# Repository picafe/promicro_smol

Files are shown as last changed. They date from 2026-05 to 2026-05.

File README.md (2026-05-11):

# promicro_smol

`promicro_smol` is a compact shield PCB for the nRF52840 Supermini/Pro Micro used in DIY SlimeVR trackers. It has an IMU, magnetometer, two buttons, RGB LED, battery pads and voltage reading functionality. It is designed to be compatible with existing Chrysalis enclosures (not yet verified). Production files can be found in `/pcb/production/`.

## Why I Made This

This project started as a modification of Chrysalis to support operation at 1.8V logic and to add a few features. The main changes were to make the magnetometer support 1.8V logic, switch to a MOSFET-controlled RGB LED, add a battery voltage divider for better capacity measurement, and to make sure SWD pads are accessible through a board cutout. I made these changes ensuring the board is optimized for JLCPCB economic assembly.

## Pictures

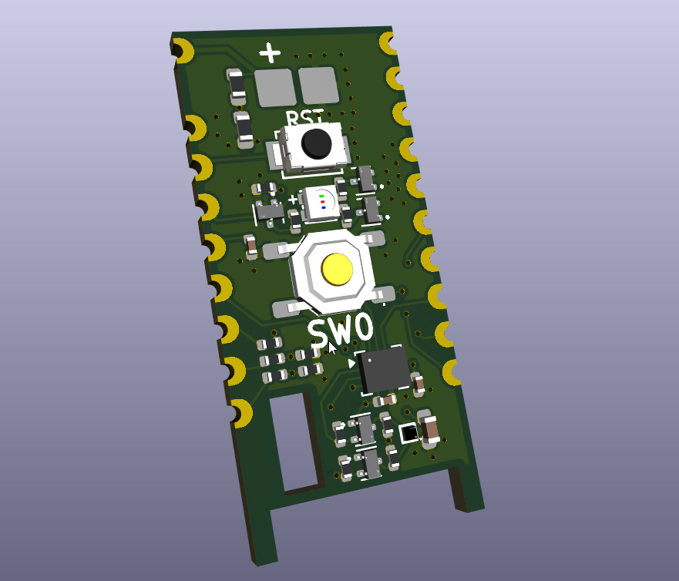
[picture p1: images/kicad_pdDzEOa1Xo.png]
3D Model


### Schematic
[View Online](https://kicanvas.org/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)

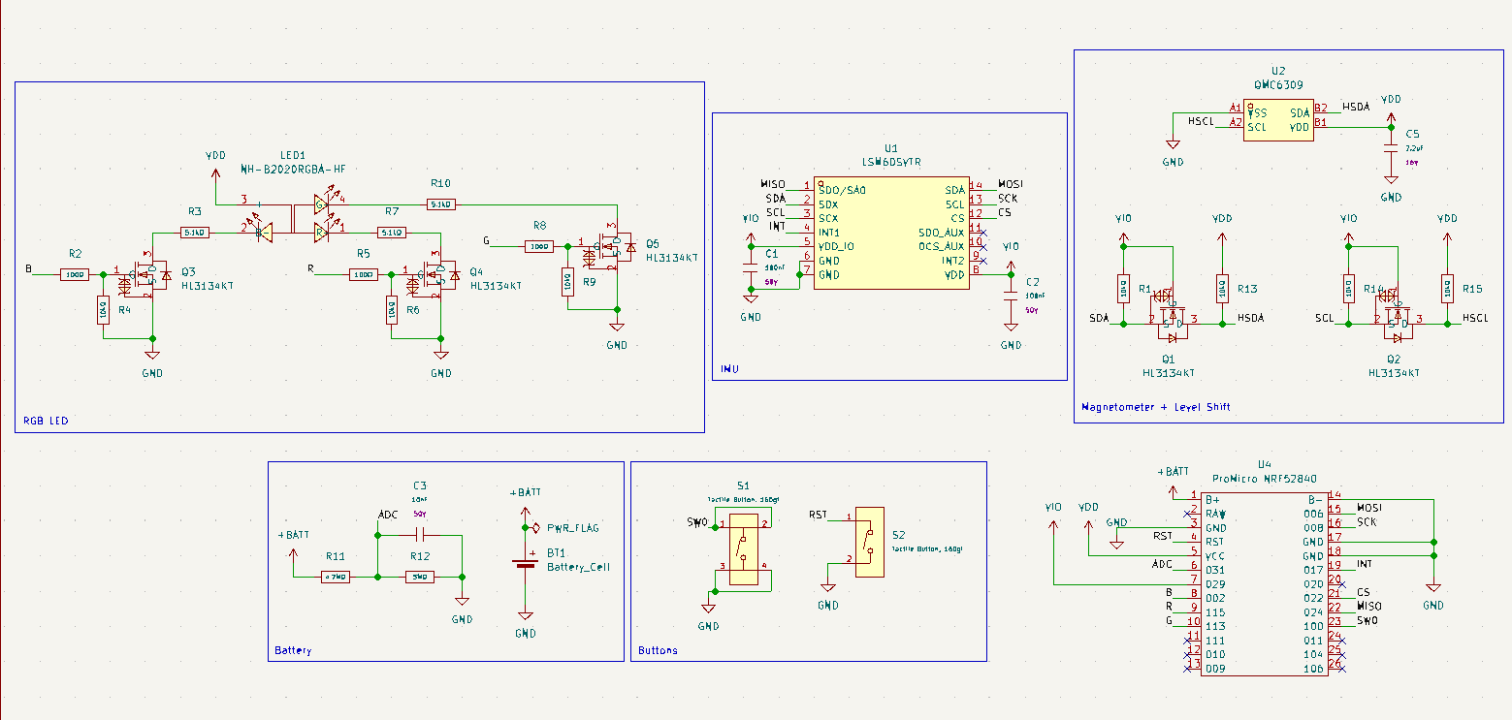
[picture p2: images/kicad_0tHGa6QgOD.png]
Schematic Image

### PCB
[View Online](https://kicanvas.org/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)

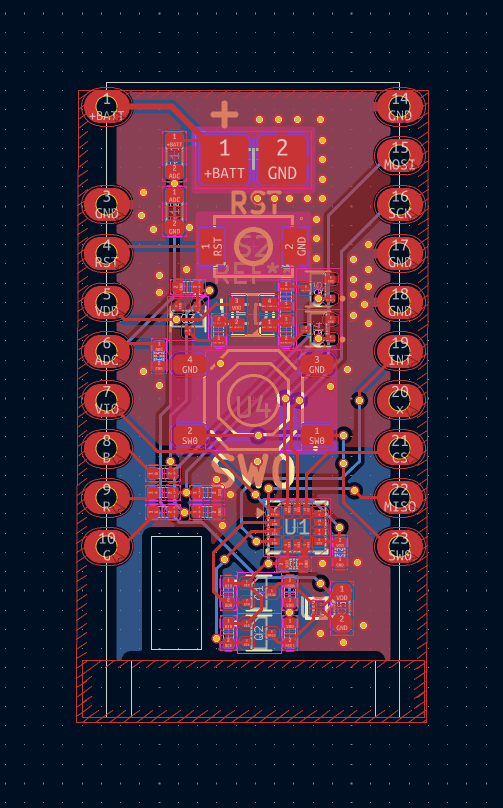
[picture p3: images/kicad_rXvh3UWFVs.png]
PCB Image


## Credits and Attribution

This work is derived from the [kounocom/Chrysalis](https://github.com/kounocom/Chrysalis) hardware project.

Files from `/pcb/Chrysalis-Footprints.pretty` are sourced from the Chrysalis project with and without modifications.

The upstream project is provided under CERN-OHL-S-2.0, and this repository includes the applicable license text in `LICENSE.md`.

## Bill of Materials

LCSC and other supplier pricing moves with stock, demand, quantity, and exchange rates. Treat **Unit cost** and **Total cost** as a very rough estimate. For example, the LSM6DSV has increased in price significantly in the past few months due to shortages and decreasing stock.

| Item | Value / Part | Quantity | Unit cost | Total cost |
| --- | --- | --- | --- | --- |
| MCU module | ProMicro nRF52840 (can be found on Aliexpress) | 1 | $3 | $3 |
| IMU | [LSM6DSVQTR (C17496470)](https://www.lcsc.com/product-detail/C17496470.html) | 1 | $2.27 | $2.27 |
| Magnetometer | [QMC6309 (C5439871)](https://www.lcsc.com/product-detail/C5439871.html) | 1 | $0.36 | $0.36 |
| N-FETs | [HL3134KT (C52204685)](https://www.lcsc.com/product-detail/C52204685.html) | 5 | $0.03 | $0.15 |
| RGB LED | [NH-B2020RGBA-HF (C2874116)](https://www.lcsc.com/product-detail/C2874116.html) | 1 | $0.01 | $0.01 |
| Push buttons | [Tactile Button, 160gf (C318884)](https://www.lcsc.com/product-detail/C318884.html), [Tactile Button, 160gf (C720477)](https://www.lcsc.com/product-detail/C720477.html) | 2 | $0.07 | $0.14 |
| Resistors | [100R (C25076)](https://www.lcsc.com/product-detail/C25076.html), [5.1k (C25905)](https://www.lcsc.com/product-detail/C25905.html), [10k (C25744)](https://www.lcsc.com/product-detail/C25744.html), [3M (C23156)](https://www.lcsc.com/product-detail/C23156.html), [4.7M (C23163)](https://www.lcsc.com/product-detail/C23163.html) | 12 | $0.01 | $0.12 |
| Capacitors | [100nF (C307331)](https://www.lcsc.com/product-detail/C307331.html), [10nF (C15195)](https://www.lcsc.com/product-detail/C15195.html), [2.2uF (C23630)](https://www.lcsc.com/product-detail/C23630.html) | 4 | $0.01 | $0.04 |

**Approximate component cost for 1 board:** ~$6.09

**PCB fabrication and assembly:** JLCPCB, 2 boards PCBA, 0.8 mm, lead-free HASL — about US$40 (your quote will differ).

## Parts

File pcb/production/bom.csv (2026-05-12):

Designator | Footprint | Quantity | Value | LCSC Part #
C1, C2 | C_0402 | 2 | 100nF | C307331
C3 | C_0402 | 1 | 10nF | C15195
C5 | C_0603 | 1 | 2.2uF | C23630
LED1 | LED-ARRAY-SMD_4P-L2.1-W2.1-TL_NH-B2020RGBA | 1 | NH-B2020RGBA-HF | C2874116
Q1, Q2, Q3, Q4, Q5 | SOT-523 | 5 | HL3134KT | C52204685
R1, R13, R14, R15, R4, R6, R9 | R_0402 | 7 | 10kΩ | C25744
R10, R3, R7 | R_0402 | 3 | 5.1kΩ | C25905
R11 | R_0603 | 1 | 5.1MΩ | C13320
R12 | R_0603 | 1 | 3MΩ | C23156
R2, R5, R8 | R_0402 | 3 | 100Ω | C25076
S1 | SW-SMD_4P-L5.1-W5.1-P3.70-LS6.5-TL-2 | 1 | Tactile Button, 160gf | C318884
S2 | SW-SMD_L3.9-W3.0-P4.45 | 1 | Tactile Button, 160gf | C720477
U1 | LGA-14_3x2.5mm_P0.5mm_LayoutBorder3x4y | 1 | LSM6DSVTR | C5267399
U2 | X1-WLB0808-4_L0.8-W0.8-P0.40-TL | 1 | QMC6309 | C5439871
U4 | Supermini nRF52840 | 1 | ProMicro NRF52840

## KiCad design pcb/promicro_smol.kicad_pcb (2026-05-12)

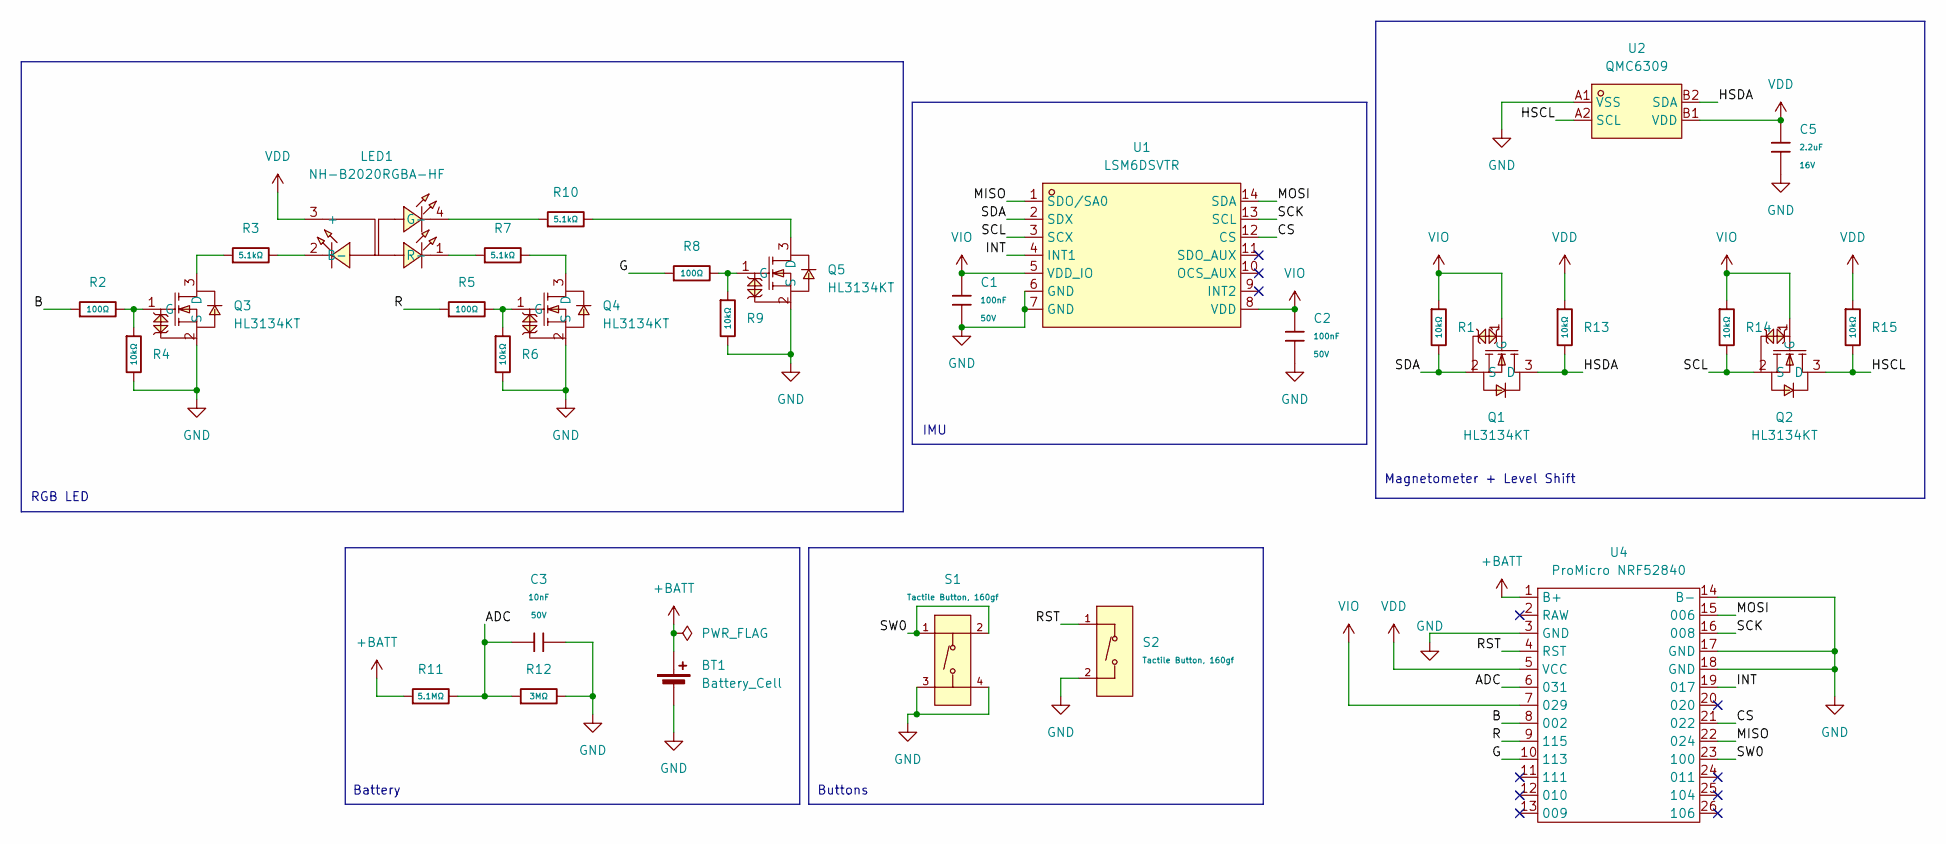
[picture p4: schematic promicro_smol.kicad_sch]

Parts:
BT1: Battery_Cell; Bat_Pads
C1, C2: 100nF; C_0402; Voltage Rated 50V; Tolerance ±10%; Part CL05B104KB54PNC; LCSC C307331
C3: 10nF; C_0402; Voltage Rated 50V; Tolerance ±10%; Part CL05B103KB5NNNC; LCSC C15195
C5: 2.2uF; C_0603; Voltage Rated 16V; Tolerance ±10%; Part CL10A225KO8NNNC; LCSC C23630
LED1: NH-B2020RGBA-HF; LED-ARRAY-SMD_4P-L2.1-W2.1-TL_NH-B2020RGBA; MPN NH-B2020RGBA-HF; LCSC Part C2874116
Q1, Q2, Q3, Q4, Q5: HL3134KT; SOT-523; MPN HL3134KT; LCSC Part C52204685
R1, R4, R6, R9, R13, R14, R15: 10kΩ; R_0402; Overload Voltage (Max) 50V; Tolerance ±1%; Part 0402WGF1002TCE; LCSC C25744
R2, R5, R8: 100Ω; R_0402; Overload Voltage (Max) 50V; Tolerance ±1%; Part 0402WGF1000TCE; LCSC C25076
R3, R7, R10: 5.1kΩ; R_0402; Overload Voltage (Max) 50V; Tolerance ±1%; Part 0402WGF5101TCE; LCSC C25905
R11: 5.1MΩ; R_0603; Overload Voltage (Max) 75V; Tolerance ±1%; Part 0603WAF5104T5E; LCSC C13320
R12: 3MΩ; R_0603; Overload Voltage (Max) 75V; Tolerance ±1%; Part 0603WAF3004T5E; LCSC C23156
S1: Tactile Button, 160gf; SW-SMD_4P-L5.1-W5.1-P3.70-LS6.5-TL-2; Voltage Rating (Dc) 12V; Part TS-1187A-B-A-B; LCSC C318884
S2: Tactile Button, 160gf; SW-SMD_L3.9-W3.0-P4.45; Voltage Rating (Dc) 12V; Part TS-1088-AR02016; LCSC C720477
U1: LSM6DSVTR; LGA-14_3x2.5mm_P0.5mm_LayoutBorder3x4y; MPN LSM6DSVTR; LCSC Part C5267399
U2: QMC6309; X1-WLB0808-4_L0.8-W0.8-P0.40-TL; MPN QMC6309; LCSC Part C5439871
U4: ProMicro NRF52840; Supermini nRF52840

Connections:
+BATT: BT1.1 (+), R11.1, U4.1 (B+)
/ADC: C3.1, R11.2, R12.1, U4.6 (031)
/B: R2.1, U4.8 (002)
/CS: U1.12 (CS), U4.21 (022)
/G: R8.1, U4.10 (113)
/HSCL: Q2.3 (D), R15.2, U2.A2 (SCL)
/HSDA: Q1.3 (D), R13.2, U2.B2 (SDA)
/INT: U1.4 (INT1), U4.19 (017)
/MISO: U1.1 (SDO/SA0), U4.22 (024)
/MOSI: U1.14 (SDA), U4.15 (006)
/R: R5.1, U4.9 (115)
/RST: S2.1 (A), U4.4 (RST)
/SCK: U1.13 (SCL), U4.16 (008)
/SCL: Q2.2 (S), R14.2, U1.3 (SCX)
/SDA: Q1.2 (S), R1.2, U1.2 (SDX)
/SW0: S1.1 (A), S1.2 (B), U4.23 (100)
GND: BT1.2 (-), C1.1, C2.1, C3.2, C5.2, Q3.2 (S), Q4.2 (S), Q5.2 (S), R4.2, R6.2, R9.2, R12.2, S1.3 (C), S1.4 (D), S2.2 (B), U1.6 (GND), U1.7 (GND), U2.A1 (VSS), U4.3 (GND), U4.14 (B-), U4.17 (GND), U4.18 (GND)
unnamed: LED1.2 (B-), R3.2
unnamed: LED1.4 (G-), R10.1
unnamed: LED1.1 (R-), R7.1
unnamed: Q3.3 (D), R3.1
unnamed: Q3.1 (G), R2.2, R4.1
unnamed: Q4.3 (D), R7.2
unnamed: Q4.1 (G), R5.2, R6.1
unnamed: Q5.3 (D), R10.2
unnamed: Q5.1 (G), R8.2, R9.1
VDD: C5.1, LED1.3 (+), R13.1, R15.1, U2.B1 (VDD), U4.5 (VCC)
VIO: C1.2, C2.2, Q1.1 (G), Q2.1 (G), R1.1, R14.1, U1.5 (VDD_IO), U1.8 (VDD), U4.7 (029)

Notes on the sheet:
Battery
Buttons
Magnetometer + Level Shift
IMU
RGB LED

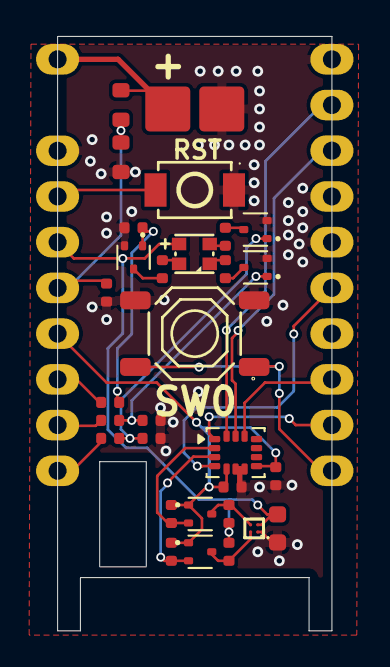
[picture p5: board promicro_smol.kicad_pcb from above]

Board: 2 copper layers, 15.2 x 33.0 mm, 31 parts (0 on the bottom side), 28 nets.

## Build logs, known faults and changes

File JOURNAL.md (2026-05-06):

# 05-01-2026 - Project kickoff and goals
I started this project as a modification of the existing Chrysalis board, which is a carrier board for the NRF52840-based Pro Micro which adds an IMU, magnetometer, and buttons. However, the magnetometer used (QMC6309) only works on 3V3 (which is fine since the Pro Micro has an external 3V3 regulator on VCC instead of the actual NRF52840 VCC). However, its logic is also at 3V3, meaning that the NRF52840 had to run at 3V3.

I wanted to make something compatible with 1V8 logic, which is supposedly more power efficient. So, I wanted to add level shifting the magnetometer I2C and use mosfets to control each channel of the RGB LED. I also decided to add a voltage divider battery monitor to a spare ADC pin. Moreover, I also wanted a cutout on the board to access the SWD pads of the Pro Micro. I used reference schematics from the Chrysalis to get started, and spent some time selecting mosfets for the led control that were in JLC's basic library. I also used the Pro Micro and Battery pads footprint from the Chrysalis to get started.

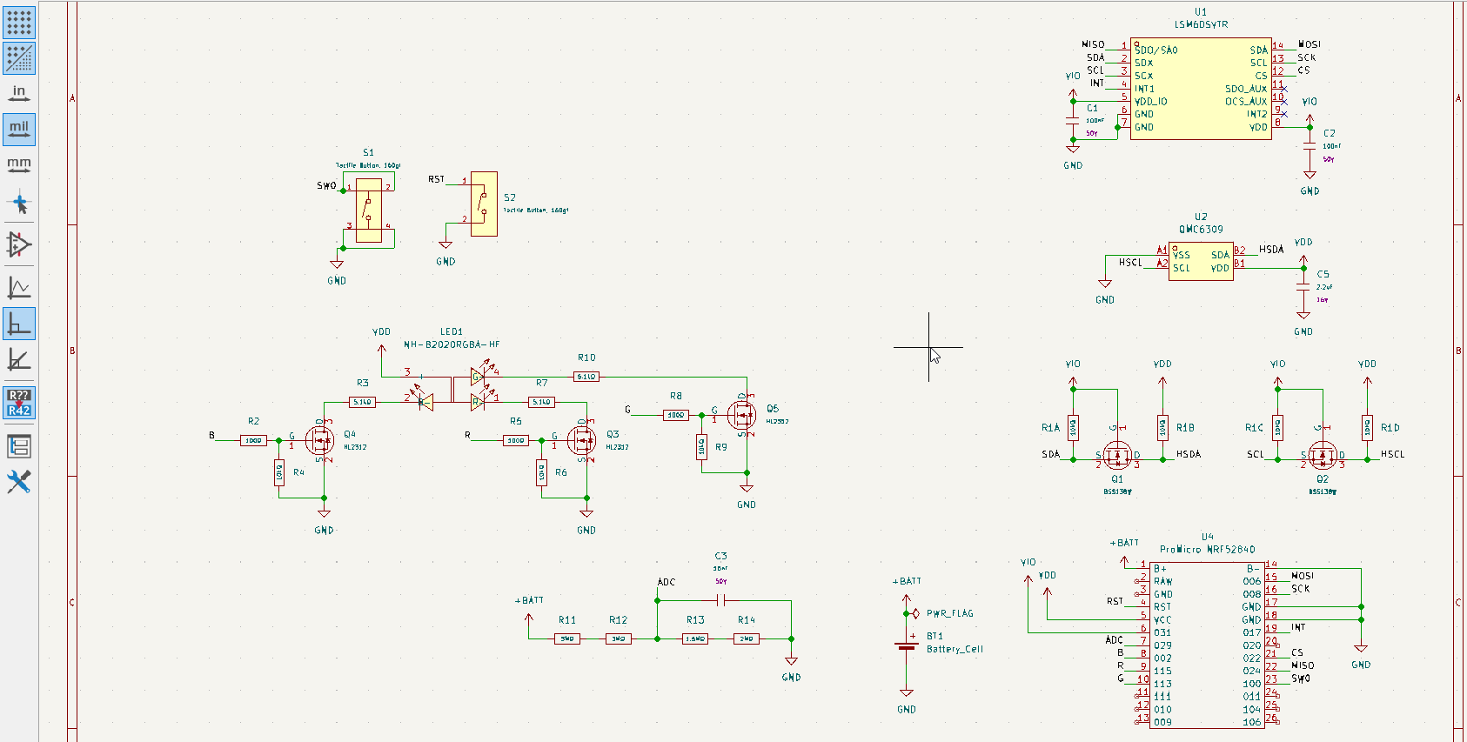
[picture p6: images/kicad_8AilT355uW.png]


`Total time spent: 3 hours`

# 05-04-2026 - Routing start and MOSFET swap
I began routing the board, starting with components that needed to be fixed. I wanted to maintain the same essential layout of the Chrysalis since there were already a couple compatible enclosures. However, I quickly realized the SOT-23 mosfets I selected for the LED control were too large for the board, and would require a lot of extra space. I decided to use the smaller SOT-523 mosfets (which I didn't know existed, just thought the smallest was SOT-323). I also decided to use the same mosfets (HL3134KT) for level shifting since they seemed better spec-wise than the BSS138. 
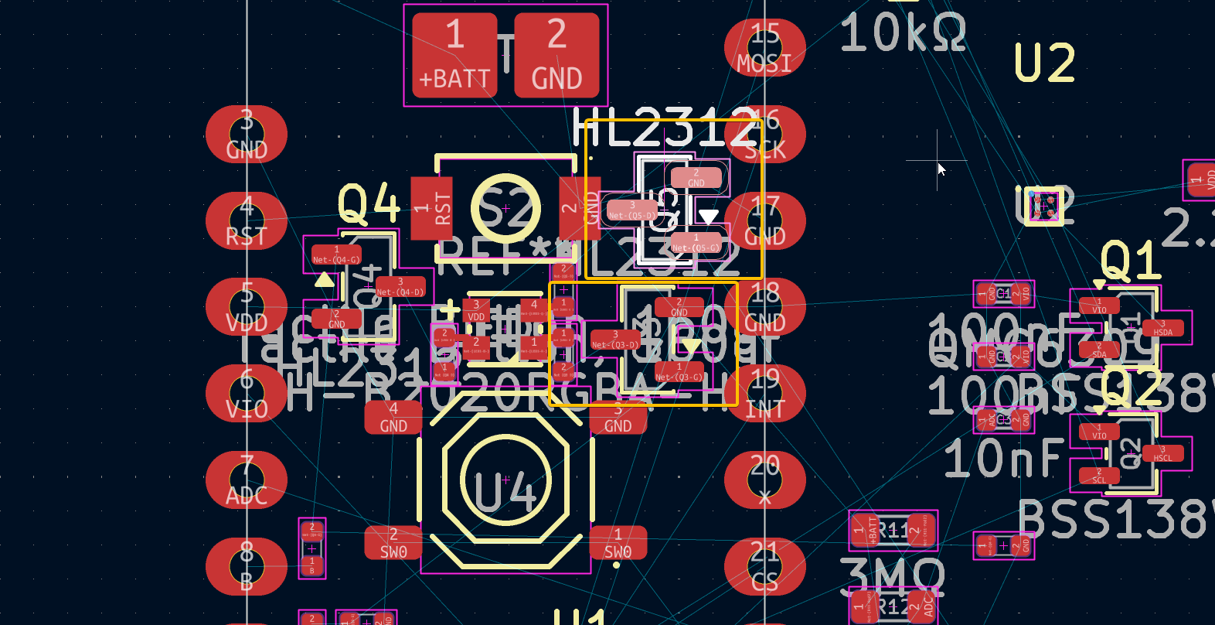
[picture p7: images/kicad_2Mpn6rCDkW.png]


This was a lot better:
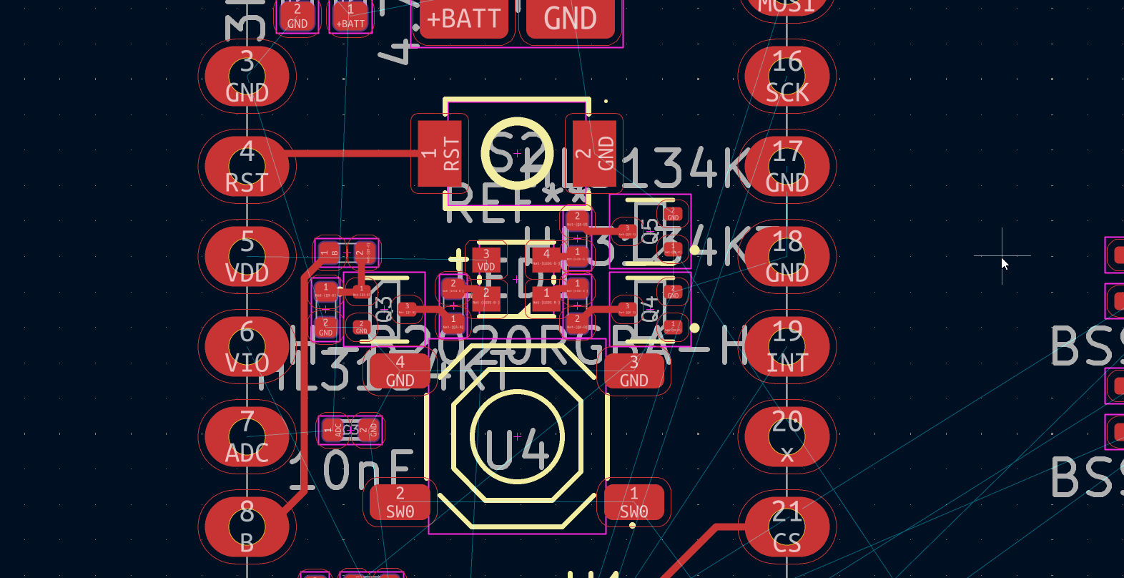
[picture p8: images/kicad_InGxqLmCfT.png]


`Total time spent: 3 hours`

# 05-05-2026 - Ground plane routing grind
I continued routing the board, which was pretty painful due to the small size and large space b/t components. I had to do a lot of rerouting to avoid making half the board an island for the ground plane. 
ex:
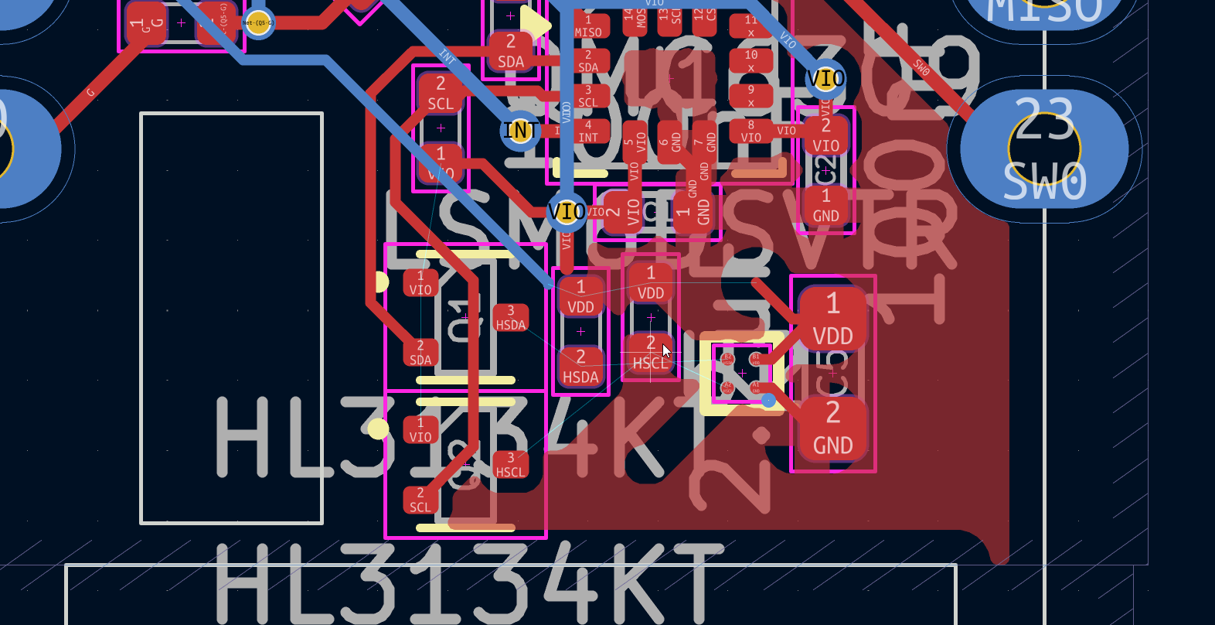
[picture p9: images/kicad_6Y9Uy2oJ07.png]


Getting the plane to span the board was quite challenging in general. I re-routed the bottom half twice to make sure everything could be connected and the ground plane could still span. It also took several iterations of moving components around for more compact routing. Although there's still a few islands, it is not as bad as it was. I eventually ended up finishing the routing.

`Total time spent: 4 hours`

# 05-06-2026 - Silkscreen and schematic cleanup
I did a few silkscreen finishing touches in terms of the PCB and cleaned up the schematic.
PCB:

SCH:

3D:


`Total time spent: 0.5 hours`

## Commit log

2026-05-10 fix: filenames, minor routing
    [promicro_smol.kicad_pcb]
2026-05-10 feat: restructure + readme + gerbers
    [bom.csv, designators.csv, positions.csv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]
2026-05-12 feat: routing + ADC res
    [bom.csv, positions.csv, promicro_smol.kicad_pcb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]
2026-05-12 fix: weird gnd pour
    [promicro_smol.kicad_pcb]
